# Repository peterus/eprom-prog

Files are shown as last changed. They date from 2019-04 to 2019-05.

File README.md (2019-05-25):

# EPROM Burner

Here you will find the circuit and the source code for a EPROM burner/programer.
This project can be used to program the famous 27/27Cxxx EPROM family.
With this circuit and software you will be able to write and read from an EPROM.

Additional to the provided hardware you will need a Arduino MEGA.
The provided circuit is easy to solder by our own with through hole components - no SMD soldering required!
I have some spare PCBs, you can contact me to get some.

## schematic

You can find the Eagle schematic in the 'schematic' folder.
Aditional you will need a Arduino MEGA board.

## source code

The source code can be found in the folder 'src', 'AVRhal' and some test-programs in 'test'.
The build system is cmake.

### compile

To compile the source code follow this steps:

   mkdir build && cd build
   cmake ..
   make
   
### flash the AVR/Arduino

   make upload_EPROM-PROG

## supported EPROMs

- 27C16 (not tested)
- 27C32 (not tested)
- 27C64 (not tested)
- 27C128 (not tested)
- 27C256 (not tested)
- 27C512 (not tested)
- 27C1001 (not tested)
- 27C2001 (not tested)
- 27C4001 (not tested)
- 27C801 (not tested)

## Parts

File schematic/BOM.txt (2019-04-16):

Stückliste exportiert aus /home/pbuchegger/project/eprom-prog/schematic/eprom_prog.sch am 16.04.19 19:44

Part         Value               Device              Package              Description                          MF MPN               OC_FARNELL OC_NEWARK
B1           ARDUINO_MEGA_R3FULL ARDUINO_MEGA_R3FULL ARDUINO_MEGA_NO_SILK Arduino Mega R3                                                               
C1           100n                C-EU050-024X044     C050-024X044         CAPACITOR, European symbol                                                    
C2           220uF               CPOL-EUE2.5-6       E2,5-6               POLARIZED CAPACITOR, European symbol                                          
C3           100n                C-EU050-024X044     C050-024X044         CAPACITOR, European symbol                                                    
C4           220uF               CPOL-EUE2.5-6       E2,5-6               POLARIZED CAPACITOR, European symbol                                          
C5           750p                C-EU050-024X044     C050-024X044         CAPACITOR, European symbol                                                    
C6           220uF               CPOL-EUE2.5-6       E2,5-6               POLARIZED CAPACITOR, European symbol                                          
D1           1N4148              1N4148DO35-7        DO35-7               DIODE                                                                         
D2           1N4148              1N4148DO35-7        DO35-7               DIODE                                                                         
D3           1N4148              1N4148DO35-7        DO35-7               DIODE                                                                         
D4           1N4148              1N4148DO35-7        DO35-7               DIODE                                                                         
D5           1N5819-B            1N5819-B            DO41-7.6             1.0A SCHOTTKY BARRIER RECTIFIER                                               
D6           1N4148              1N4148DO35-7        DO35-7               DIODE                                                                         
D7           1N4148              1N4148DO35-7        DO35-7               DIODE                                                                         
GOLD_ORB_SM1 OSHWLOGOLOGO8MM     OSHWLOGOLOGO8MM     OSHW_8MM             The OSHW logo for PCB layout                                                  
IC1          MC33063/MC34063P    MC33063/MC34063P    DIL08                MC33063 and MC34063                                                           
K1           G5V1                G5V1                G5V1                 RELAY                                   G5V-1-DC24        9949593    36M6377  
K2           G5V1                G5V1                G5V1                 RELAY                                   G5V-1-DC24        9949593    36M6377  
K3           G5V1                G5V1                G5V1                 RELAY                                   G5V-1-DC24        9949593    36M6377  
K4           G5V1                G5V1                G5V1                 RELAY                                   G5V-1-DC24        9949593    36M6377  
K5           G5V1                G5V1                G5V1                 RELAY                                   G5V-1-DC24        9949593    36M6377  
K6           G5V1                G5V1                G5V1                 RELAY                                   G5V-1-DC24        9949593    36M6377  
L1           220uH               SD12-1000           SD12_1000            INDUCTOR                                                  unknown    unknown  
Q1           BS170               BS170               SOT54E               N-CHANNEL MOS FET                                                             
Q2           BS170               BS170               SOT54E               N-CHANNEL MOS FET                                                             
Q3           BS170               BS170               SOT54E               N-CHANNEL MOS FET                                                             
Q4           BS170               BS170               SOT54E               N-CHANNEL MOS FET                                                             
Q5           BS170               BS170               SOT54E               N-CHANNEL MOS FET                                                             
Q6           BS170               BS170               SOT54E               N-CHANNEL MOS FET                                                             
Q7           BC557               BC557               TO92                 PNP Transistor                                                                
Q8           BS170               BS170               SOT54E               N-CHANNEL MOS FET                                                             
Q9           BS170               BS170               SOT54E               N-CHANNEL MOS FET                                                             
R1           3k3                 R-EU_0207/2V        0207/2V              RESISTOR, European symbol                                                     
R2           3k3                 R-EU_0207/2V        0207/2V              RESISTOR, European symbol                                                     
R3           3k3                 R-EU_0207/2V        0207/2V              RESISTOR, European symbol                                                     
R4           620                 R-EU_0207/2V        0207/2V              RESISTOR, European symbol                                                     
R5           180                 R-EU_0207/2V        0207/2V              RESISTOR, European symbol                                                     
R6           3k3                 R-EU_0207/2V        0207/2V              RESISTOR, European symbol                                                     
R7           3k3                 R-EU_0207/2V        0207/2V              RESISTOR, European symbol                                                     
R8           0.3                 R-EU_0207/2V        0207/2V              RESISTOR, European symbol                                                     
R9           3k3                 R-EU_0207/2V        0207/2V              RESISTOR, European symbol                                                     
R10          300                 R-EU_0207/2V        0207/2V              RESISTOR, European symbol                                                     
R11          1k5                 R-EU_0207/2V        0207/2V              RESISTOR, European symbol                                                     
R12          3k9                 R-EU_0207/2V        0207/2V              RESISTOR, European symbol                                                     
R13          4k7                 R-EU_0207/2V        0207/2V              RESISTOR, European symbol                                                     
R14          4k7                 R-EU_0207/2V        0207/2V              RESISTOR, European symbol                                                     
R15          3k3                 R-EU_0207/2V        0207/2V              RESISTOR, European symbol                                                     
R16          3k3                 R-EU_0207/2V        0207/2V              RESISTOR, European symbol                                                     
T1           BC547               BC547               TO92                 NPN TRANSISTOR                                                                
ZX1          232-1285-00-0602J   232-1285-00-0602J   232-1285-00-0602J    Zero Insertion Force Socked          3M 232-1285-00-0602J 9897402    85K7839

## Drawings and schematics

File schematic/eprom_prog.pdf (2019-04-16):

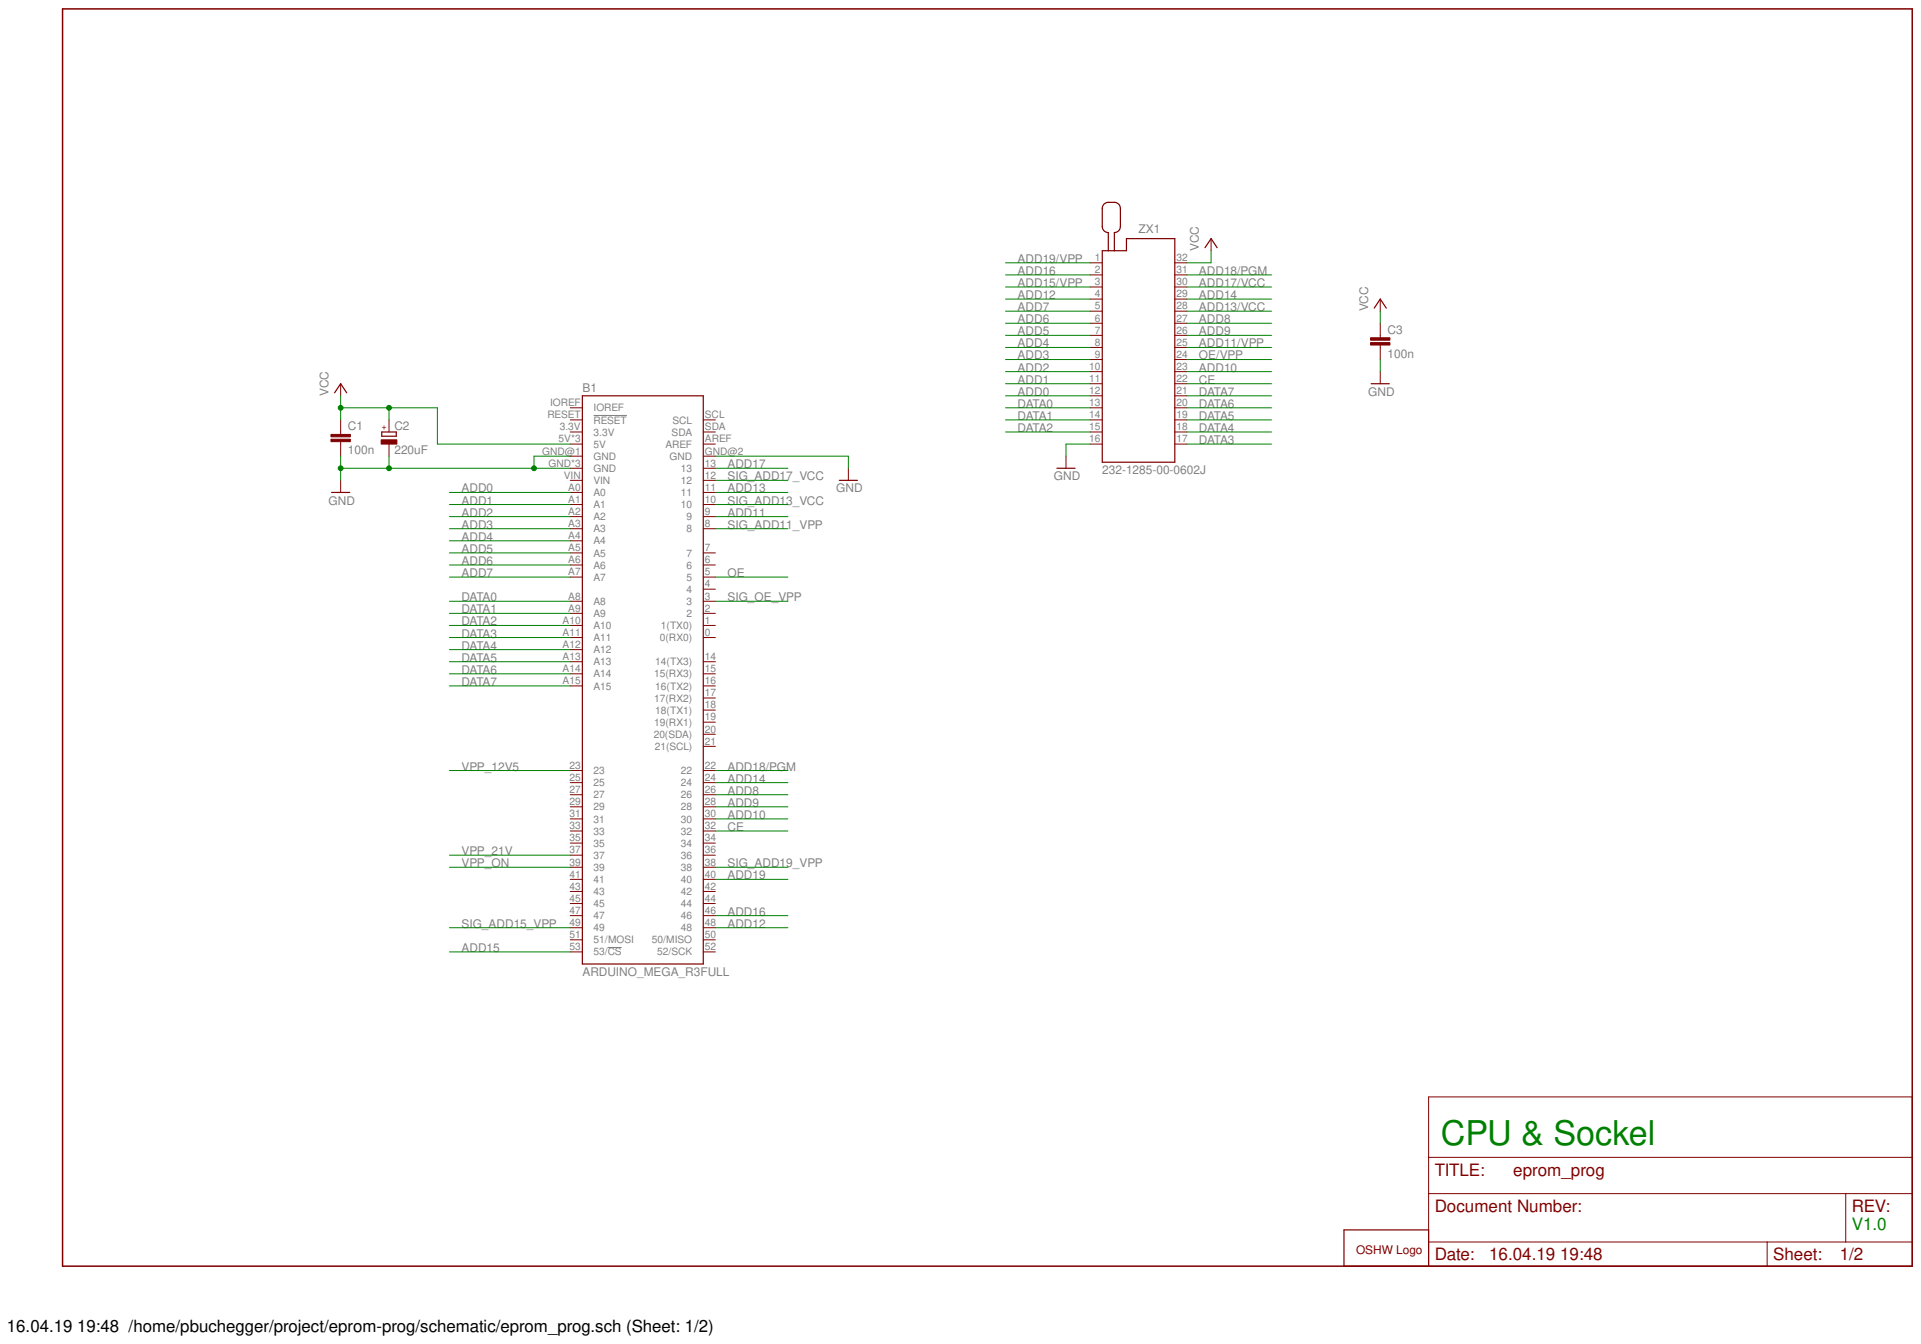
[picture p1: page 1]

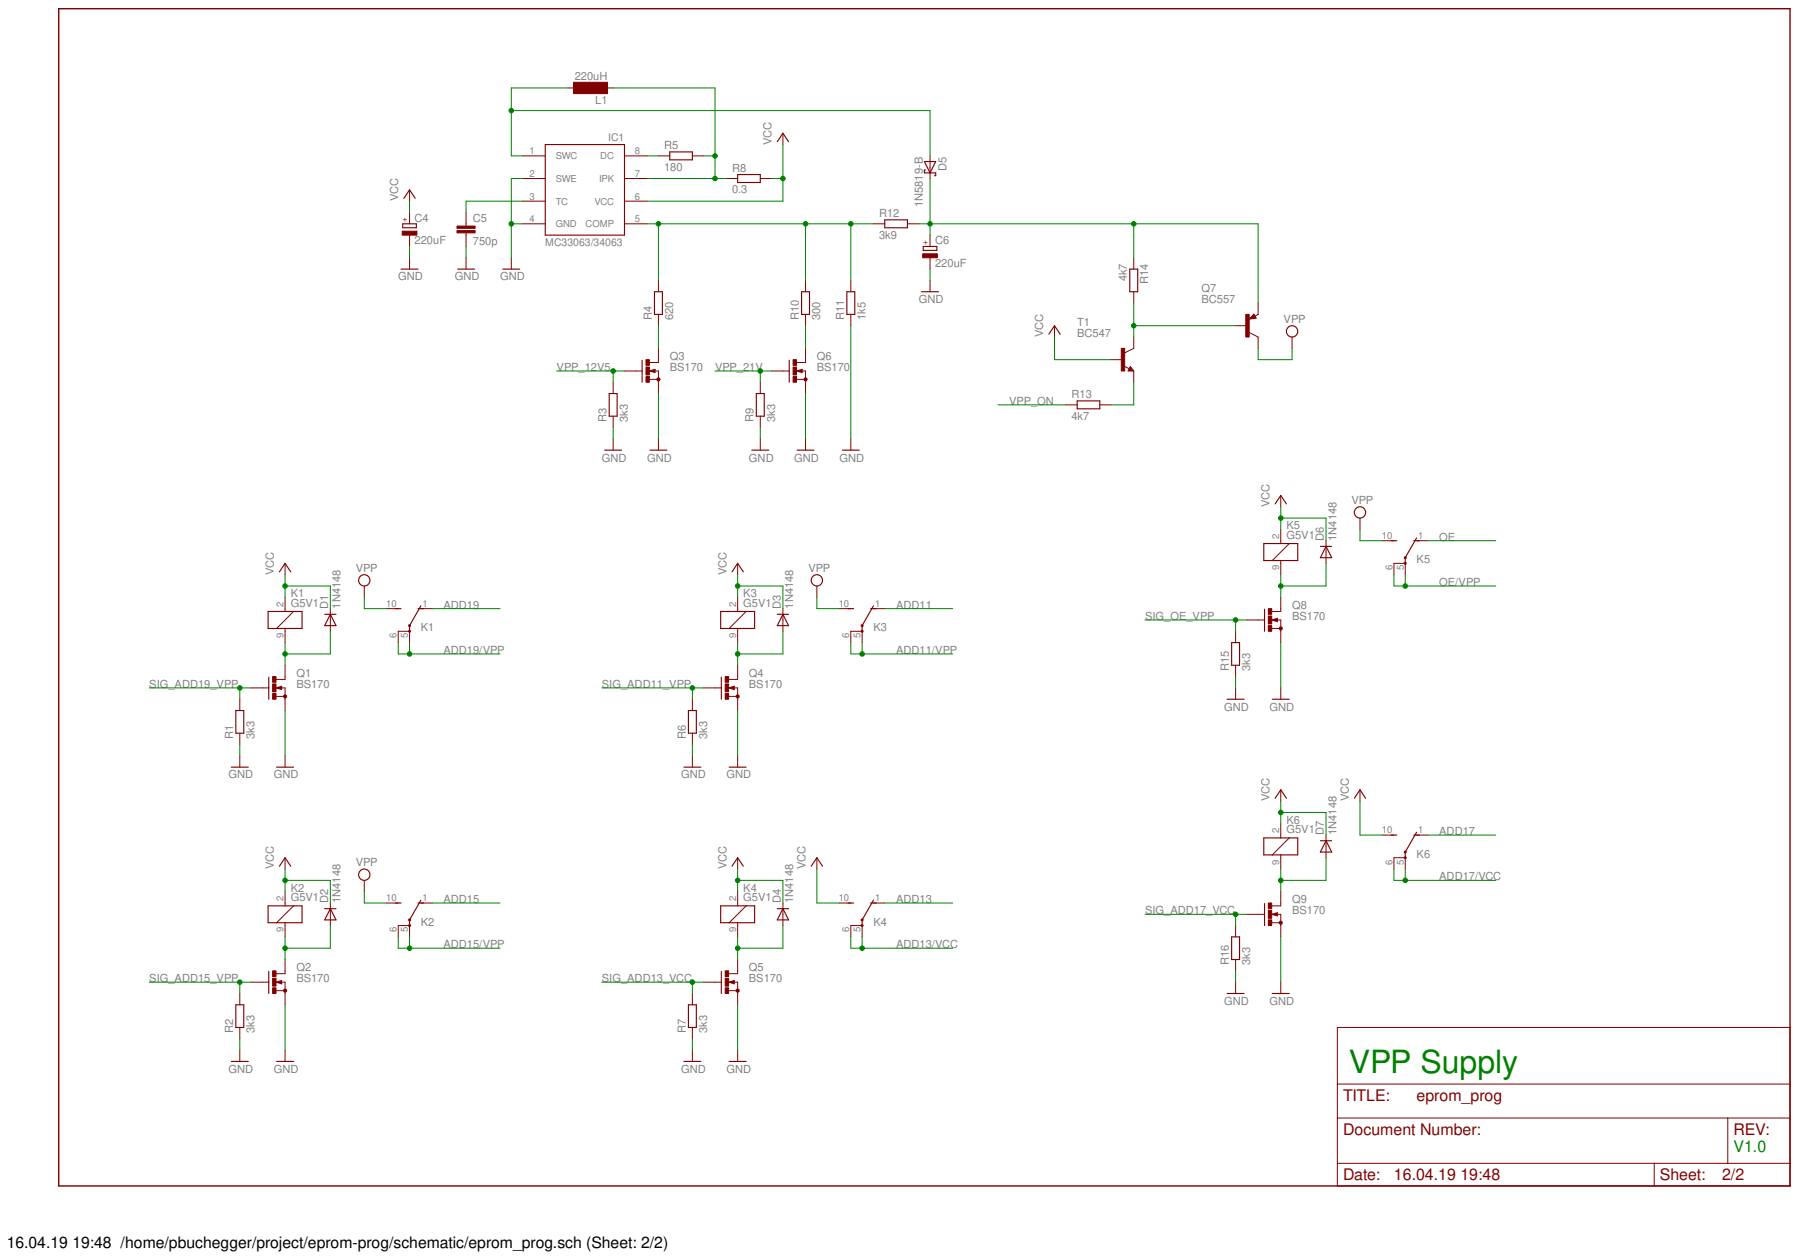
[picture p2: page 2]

Document Number: | REV: V1.0

Date: 16.04.19 19:48 | Sheet: 2/2

16.04.19 19:48 /home/pbuchegger/project/eprom-prog/schematic/eprom_prog.sch (Sheet: 2/2)

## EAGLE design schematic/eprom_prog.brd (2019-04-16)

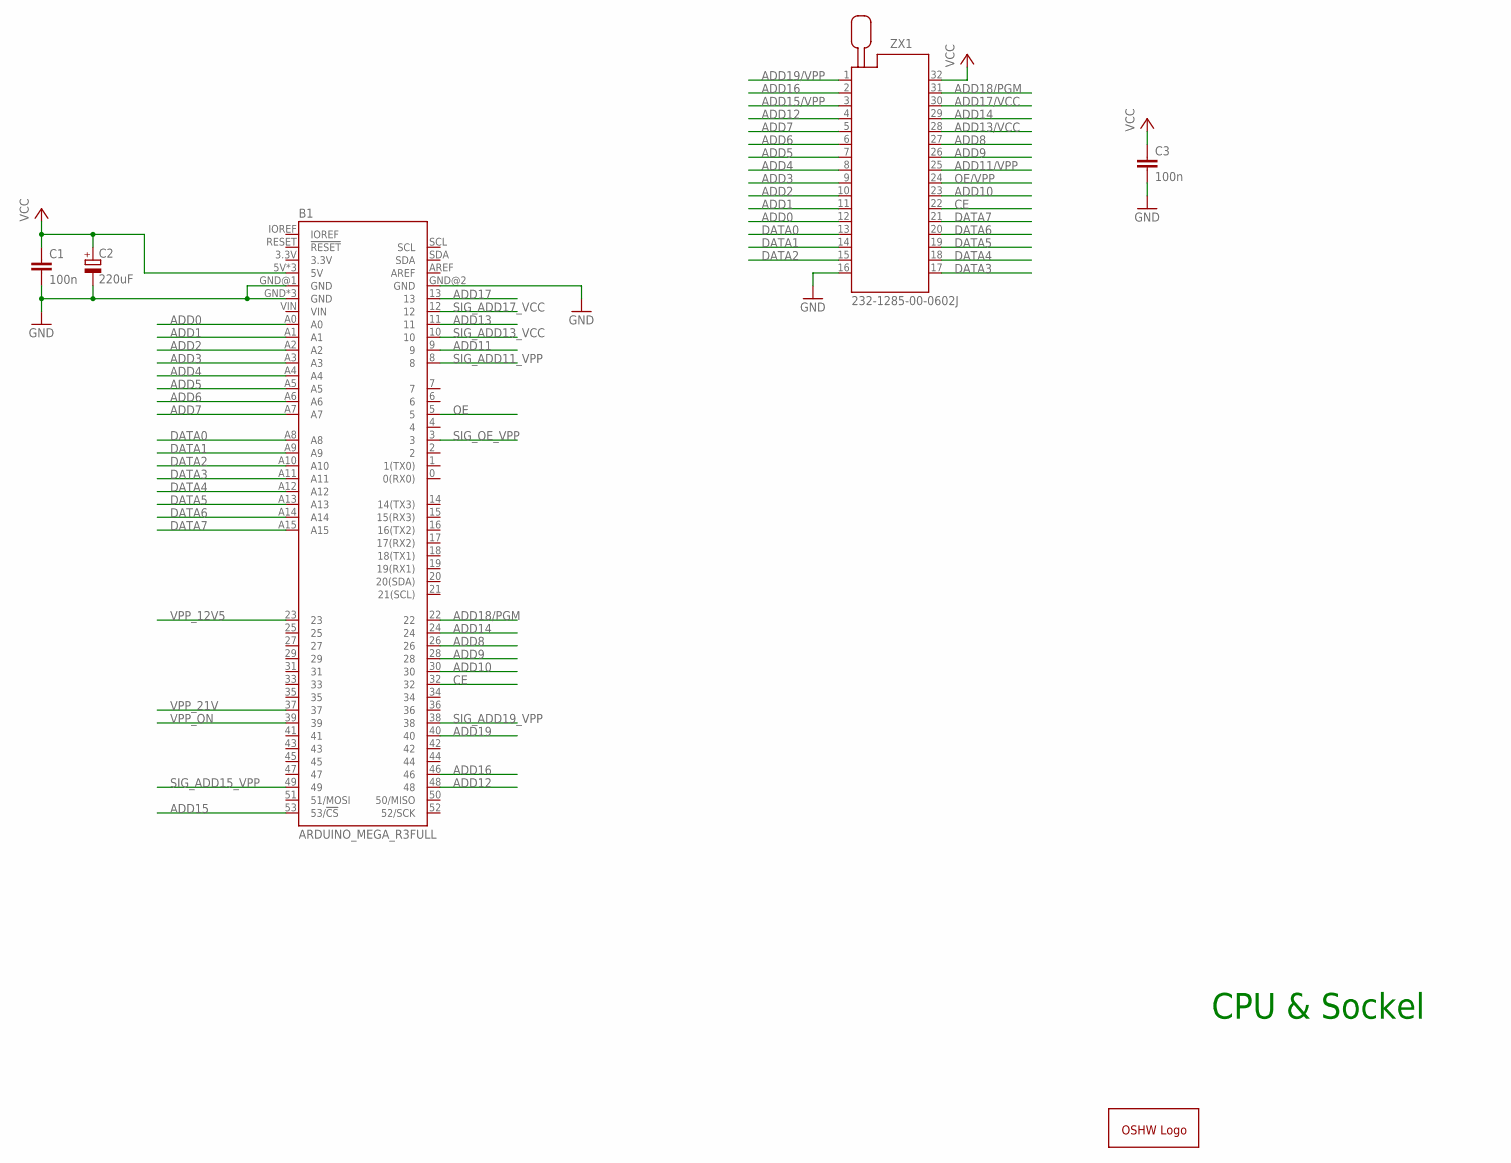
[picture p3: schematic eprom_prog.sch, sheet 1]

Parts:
B1: ARDUINO_MEGA_R3FULL; ARDUINO_MEGA_NO_SILK
C1, C3: 100n; C050-024X044
C2: 220uF; E2,5-6
GOLD_ORB_SM1: OSHWLOGOLOGO8MM; OSHW_8MM
ZX1: 232-1285-00-0602J

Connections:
ADD0: B1.A0, ZX1.12
ADD1: B1.A1, ZX1.11
ADD2: B1.A2, ZX1.10
ADD3: B1.A3, ZX1.9
ADD4: B1.A4, ZX1.8
ADD5: B1.A5, ZX1.7
ADD6: B1.A6, ZX1.6
ADD7: B1.A7, ZX1.5
ADD8: B1.26, ZX1.27
ADD9: B1.28, ZX1.26
ADD10: B1.30, ZX1.23
ADD11: B1.9; also elsewhere on the board
ADD11/VPP: ZX1.25; also elsewhere on the board
ADD12: B1.48, ZX1.4
ADD13: B1.11; also elsewhere on the board
ADD13/VCC: ZX1.28; also elsewhere on the board
ADD14: B1.24, ZX1.29
ADD15: B1.53 (53/!CS); also elsewhere on the board
ADD15/VPP: ZX1.3; also elsewhere on the board
ADD16: B1.46, ZX1.2
ADD17: B1.13; also elsewhere on the board
ADD17/VCC: ZX1.30; also elsewhere on the board
ADD18/PGM: B1.22, ZX1.31
ADD19: B1.40; also elsewhere on the board
ADD19/VPP: ZX1.1; also elsewhere on the board
CE: B1.32, ZX1.22
DATA0: B1.A8, ZX1.13
DATA1: B1.A9, ZX1.14
DATA2: B1.A10, ZX1.15
DATA3: B1.A11, ZX1.17
DATA4: B1.A12, ZX1.18
DATA5: B1.A13, ZX1.19
DATA6: B1.A14, ZX1.20
DATA7: B1.A15, ZX1.21
GND: B1.GND, B1.GND@1 (GND), B1.GND@2 (GND), B1.GND@3 (GND), B1.GND@4 (GND), C1.2, C2.-, C3.2, ZX1.16; also elsewhere on the board
OE: B1.5; also elsewhere on the board
OE/VPP: ZX1.24; also elsewhere on the board
SIG_ADD11_VPP: B1.8; also elsewhere on the board
SIG_ADD13_VCC: B1.10; also elsewhere on the board
SIG_ADD15_VPP: B1.49; also elsewhere on the board
SIG_ADD17_VCC: B1.12; also elsewhere on the board
SIG_ADD19_VPP: B1.38; also elsewhere on the board
SIG_OE_VPP: B1.3; also elsewhere on the board
VCC: B1.5V, B1.5V@1 (5V), B1.5V@2 (5V), C1.1, C2.+, C3.1, ZX1.32; also elsewhere on the board
VPP_12V5: B1.23; also elsewhere on the board
VPP_21V: B1.37; also elsewhere on the board
VPP_ON: B1.39; also elsewhere on the board

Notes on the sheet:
CPU & Sockel

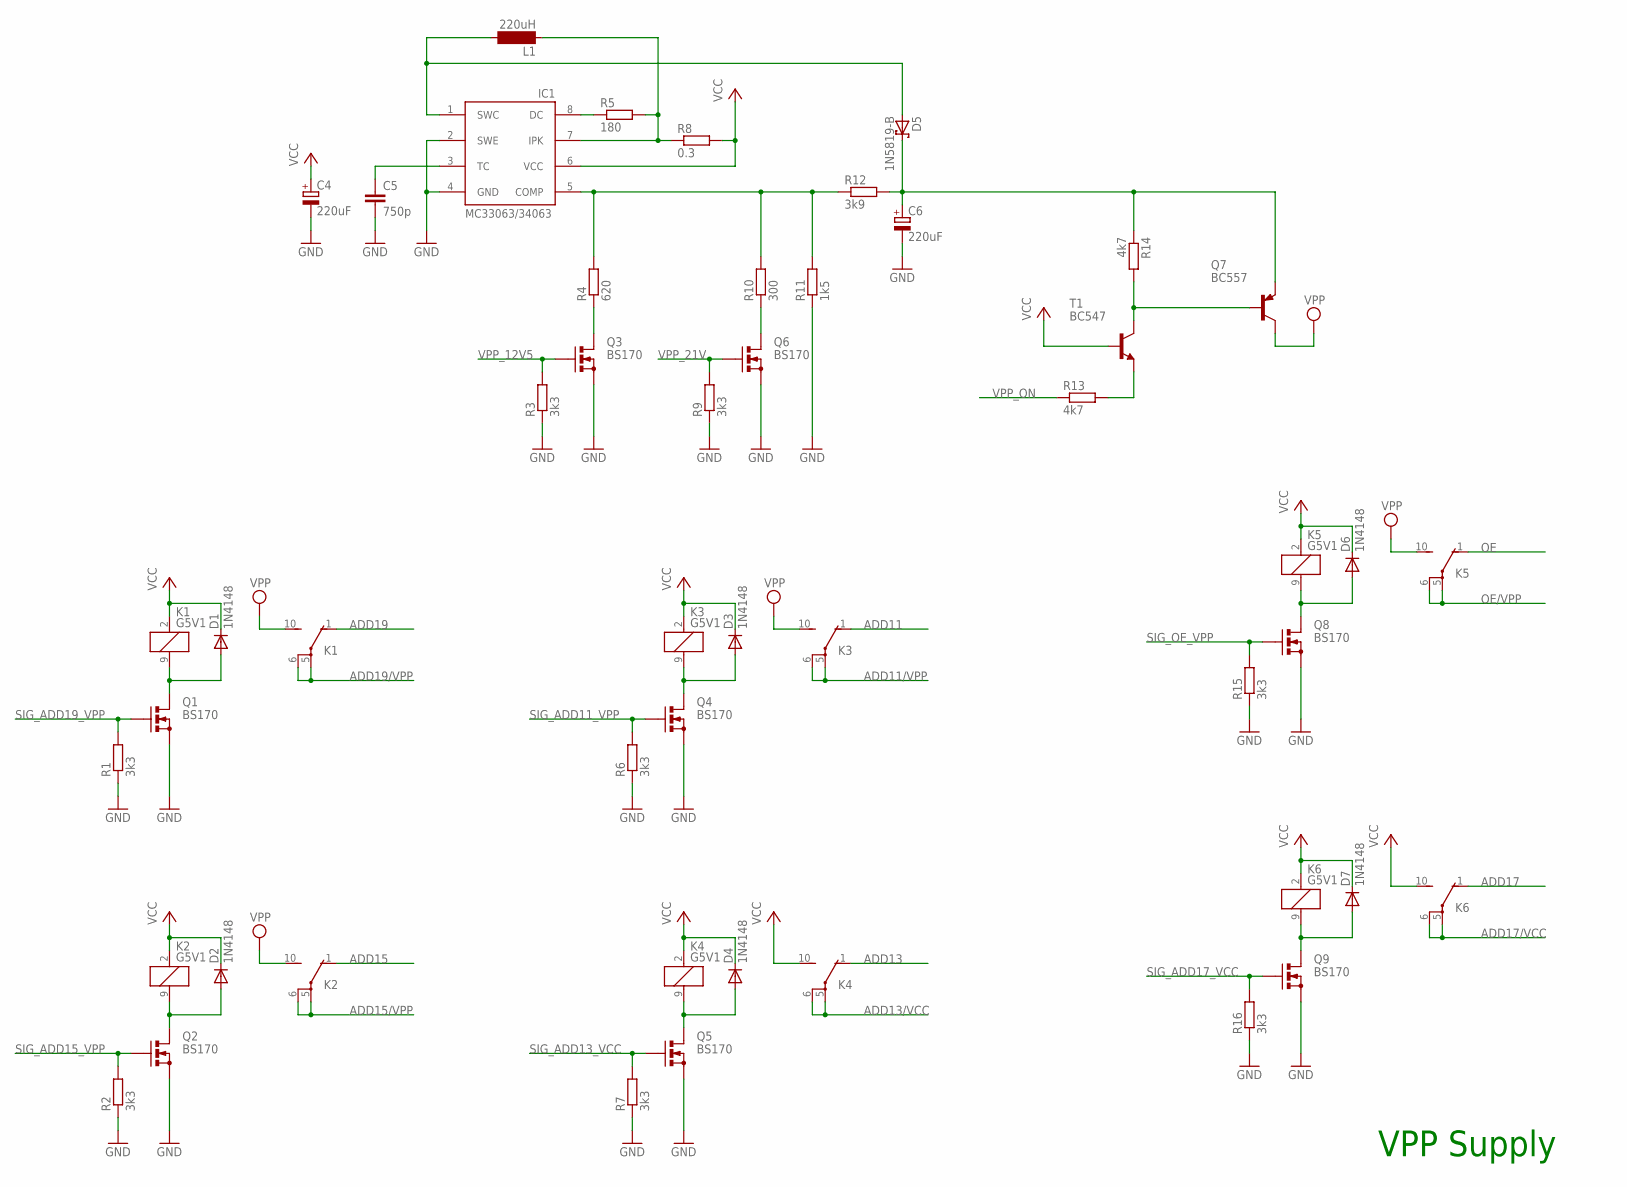
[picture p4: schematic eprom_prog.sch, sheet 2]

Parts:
C4, C6: 220uF; E2,5-6
C5: 750p; C050-024X044
D1, D2, D3, D4, D6, D7: 1N4148; DO35-7
D5: 1N5819-B; DO41-7.6
IC1: MC33063/MC34063P; DIL08
K1, K2, K3, K4, K5, K6: G5V1
L1: 220uH; SD12_1000
Q1, Q2, Q3, Q4, Q5, Q6, Q8, Q9: BS170; SOT54E
Q7: BC557; TO92
R1, R2, R3, R6, R7, R9, R15, R16: 3k3; 0207/2V
R4: 620; 0207/2V
R5: 180; 0207/2V
R8: 0.3; 0207/2V
R10: 300; 0207/2V
R11: 1k5; 0207/2V
R12: 3k9; 0207/2V
R13, R14: 4k7; 0207/2V
T1: BC547; TO92

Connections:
+VPP: C6.+, D5.C, Q7.1 (E), R12.2, R14.1
ADD11: K3.1 (O); also elsewhere on the board
ADD11/VPP: K3.5, K3.6; also elsewhere on the board
ADD13: K4.1 (O); also elsewhere on the board
ADD13/VCC: K4.5, K4.6; also elsewhere on the board
ADD15: K2.1 (O); also elsewhere on the board
ADD15/VPP: K2.5, K2.6; also elsewhere on the board
ADD17: K6.1 (O); also elsewhere on the board
ADD17/VCC: K6.5, K6.6; also elsewhere on the board
ADD19: K1.1 (O); also elsewhere on the board
ADD19/VPP: K1.5, K1.6; also elsewhere on the board
GND: C4.-, C5.2, C6.-, IC1.2 (SWE), IC1.4 (GND), Q1.S, Q2.S, Q3.S, Q4.S, Q5.S, Q6.S, Q8.S, Q9.S, R1.1, R2.1, R3.1, R6.1, R7.1, R9.1, R11.1, R15.1, R16.1; also elsewhere on the board
unnamed: D2.A, K2.9 (2), Q2.D
unnamed: IC1.7 (IPK), L1.1, R5.2, R8.1
unnamed: Q6.D, R10.1
unnamed: Q7.2 (B), R14.2, T1.3 (C)
unnamed: R13.2, T1.1 (E)
unnamed: Q3.D, R4.1
unnamed: C5.1, IC1.3 (TC)
unnamed: IC1.5 (COMP), R4.2, R10.2, R11.2, R12.1
unnamed: IC1.8 (DC), R5.1
unnamed: D5.A, IC1.1 (SWC), L1.2
unnamed: D1.A, K1.9 (2), Q1.D
unnamed: D3.A, K3.9 (2), Q4.D
unnamed: D4.A, K4.9 (2), Q5.D
unnamed: D6.A, K5.9 (2), Q8.D
unnamed: D7.A, K6.9 (2), Q9.D
OE: K5.1 (O); also elsewhere on the board
OE/VPP: K5.5, K5.6; also elsewhere on the board
SIG_ADD11_VPP: Q4.G, R6.2; also elsewhere on the board
SIG_ADD13_VCC: Q5.G, R7.2; also elsewhere on the board
SIG_ADD15_VPP: Q2.G, R2.2; also elsewhere on the board
SIG_ADD17_VCC: Q9.G, R16.2; also elsewhere on the board
SIG_ADD19_VPP: Q1.G, R1.2; also elsewhere on the board
SIG_OE_VPP: Q8.G, R15.2; also elsewhere on the board
VCC: C4.+, D1.C, D2.C, D3.C, D4.C, D6.C, D7.C, IC1.6 (VCC), K1.2 (1), K2.2 (1), K3.2 (1), K4.2 (1), K4.10 (S), K5.2 (1), K6.2 (1), K6.10 (S), R8.2, T1.2 (B); also elsewhere on the board
VPP: K1.10 (S), K2.10 (S), K3.10 (S), K5.10 (S), Q7.3 (C)
VPP_12V5: Q3.G, R3.2; also elsewhere on the board
VPP_21V: Q6.G, R9.2; also elsewhere on the board
VPP_ON: R13.1; also elsewhere on the board

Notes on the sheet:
VPP Supply

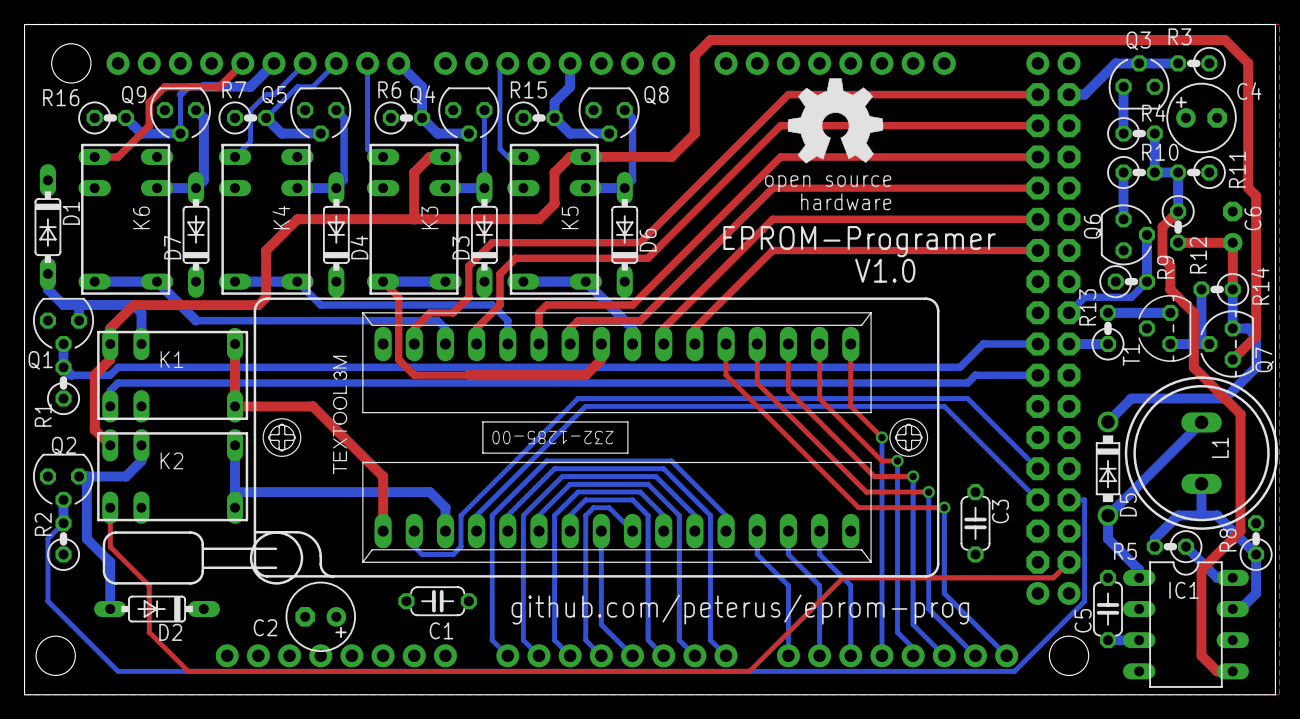
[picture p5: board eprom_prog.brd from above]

Board: 2 copper layers, 101.9 x 54.6 mm, 50 parts (1 on the bottom side), 64 nets.

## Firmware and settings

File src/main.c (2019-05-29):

/*
 * UART_Test.c
 *
 * Created: 26.10.2014 19:01:09
 *  Author: Peter Buchegger
 */ 


#include <stdint.h>
#include <stdio.h>
#include <util/delay.h>
#include "COM/UART.h"
#define _DEBUG
#include "Debug.h"
#include "System.h"

#include "io.h"
#include "27c.h"

/*************************************
---> set eprom type
1. byte: 0x01
2. byte: enum EPROM_Type { 801 = 0, 4001 = 1, 2001 = 2, 1001 = 3, 512 = 4, 256 = 5, 128 = 6, 64 = 7, 32 = 8, 16 = 9 }
3. byte: enum EPROM_VPP { 12.5V = 0, 21V = 1 }

---> set address
1. byte: 0x02
2. byte: address (higher byte)
3. byte: address (lower byte)

---> read data (with address increment)
1. byte: 0x03
2. byte: length to read in bytes

---> write data (with address increment)
1. byte 0x04
2. byte: length to write
x. byte: data

all answers are:
1. byte: 0x1.
other bytes are the same as sent
*************************************/

eprom_setting_t * eprom_setting = 0;
uint32_t address = 0;

void set_eprom_type(void)
{
	unsigned int type = 0;
	unsigned int vpp = 0;
	while((type = UART_GetC()) == UART_NO_DATA) {} // 2. byte: type
	eprom_setting = eprom_settings[type];
	
	while((vpp = UART_GetC()) == UART_NO_DATA) {} // 3. byte: vpp
	eprom_setting->vpp_power = vpp;

	address_map.size = eprom_setting->address_pins_count;
	printf("selected chip: %s\n", eprom_setting->name);

	reset_all();
	setup_power(eprom_setting);
	setup_relay(eprom_setting);
	sleep(100);

	UART_PutByte(0x11);
	UART_PutByte((uint8_t)type);
	UART_PutByte((uint8_t)vpp);
}

void set_address(void)
{
	uint8_t upper = 0;
	uint8_t lower = 0;
	unsigned int buffer = 0;
	while((buffer = UART_GetC()) == UART_NO_DATA) {} // 2. byte: address (higher byte)
	upper = buffer & 0xFF;
	while((buffer = UART_GetC()) == UART_NO_DATA) {} // 3. byte: address (lower byte)
	lower = buffer & 0xFF;

	address = upper << 8 | lower;

	UART_PutByte(0x12);
	UART_PutByte(upper);
	UART_PutByte(lower);
}

void read_data_(void)
{
	uint16_t length = 0;
	uint8_t upper = 0;
	uint8_t lower = 0;
	unsigned int buffer = 0;

	while((buffer = UART_GetC()) == UART_NO_DATA) {} // 2. byte: length (higher byte)
	upper = buffer & 0xFF;
	while((buffer = UART_GetC()) == UART_NO_DATA) {} // 3. byte: length (lower byte)
	lower = buffer & 0xFF;

	length = upper << 8 | lower;

	UART_PutByte(0x13);
	read_data_start(eprom_setting);
	for(uint16_t i = 0; i < length; i++)
	{
		uint32_t data = read_data(eprom_setting, address);
		UART_PutByte((uint8_t)data);
		address++;
	}
	read_data_end(eprom_setting);
}

void write_data_start(void)
{
	program_data_start(eprom_setting);
	UART_PutByte(0x14);
}

void write_data_(void)
{
	uint16_t length = 0;
	uint8_t upper = 0;
	uint8_t lower = 0;
	unsigned int buffer = 0;

	while((buffer = UART_GetC()) == UART_NO_DATA) {} // 2. byte: length (higher byte)
	upper = buffer & 0xFF;
	while((buffer = UART_GetC()) == UART_NO_DATA) {} // 3. byte: length (lower byte)
	lower = buffer & 0xFF;

	length = upper << 8 | lower;

	UART_PutByte(0x15);
	UART_PutByte(upper);
	UART_PutByte(lower);
	for(uint16_t i = 0; i < length; i++)
	{
		unsigned int data = 0;
		while((data = UART_GetC()) == UART_NO_DATA) {} // x. byte: data
		program_data(eprom_setting, address, (uint8_t)data);
		UART_PutByte((uint8_t)data);
		address++;
	}
}

void write_data_end(void)
{
	program_data_end(eprom_setting);
	UART_PutByte(0x16);
}

void verify_empty(void)
{
	uint8_t status = 0;
	read_data_start(eprom_setting);
	for(uint32_t i = 0; i < eprom_setting->max_data; i++)
	{
		uint32_t data = read_data(eprom_setting, i);
		if(data != 0xFF)
		{
			status = 1;
		}
	}
	read_data_end(eprom_setting);
	UART_PutByte(0x17);
	UART_PutByte(status);
}

int main(void)
{
	// 19200
	// 57600
	// 115200
	UART_Init(UART_BAUD_SELECT(57600, F_CPU));
	interrupts(1); //sei();

	reset_all();
	DEBUG_OUT("ready\n");
	
	while(1)
	{
		unsigned int c = 0;
		while((c = UART_GetC()) == UART_NO_DATA) {}

		switch(c)
		{
			case 0x01:
				set_eprom_type();
				break;
			case 0x02:
				set_address();
				break;
			case 0x03:
				read_data_();
				break;
			case 0x04:
				write_data_start();
				break;
			case 0x05:
				write_data_();
				break;
			case 0x06:
				write_data_end();
				break;
			case 0x07:
				verify_empty();
			default:
				break;
		}
	}
}

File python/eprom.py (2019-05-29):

#!/bin/python

import serial
import argparse

DEBUG = 0

eprom_settings = [
	{'name': '27C801',  'size': 2**20, 'id': 0},
	{'name': '27C4001', 'size': 2**19, 'id': 1},
	{'name': '27C2001', 'size': 2**18, 'id': 2},
	{'name': '27C1001', 'size': 2**17, 'id': 3},
	{'name': '27C512',  'size': 2**16, 'id': 4},
	{'name': '27C256',  'size': 2**15, 'id': 5},
	{'name': '27C128',  'size': 2**14, 'id': 6},
	{'name': '27C64',   'size': 2**13, 'id': 7},
	{'name': '27C32',   'size': 2**12, 'id': 8},
	{'name': '27C16',   'size': 2**11, 'id': 9}
]

def set_type(ser, type, vpp):
	print("set type:")
	values = bytearray([0x01, type, vpp])
	ser.write(values)
	print(ser.readline())
	s = ser.read(3)
	if DEBUG == 1:
		for key, x in enumerate(s):
			print("%i: 0x%0.2X" % (key, x))
	if s[0] != 0x11 or s[1] != type or s[2] != vpp:
		raise Exception('set_type', 'readback is not okay')

def set_address(ser, address):
	print("set address:")
	upper = (address >> 8) & 0xFF
	lower = address & 0xFF
	values = bytearray([0x02, upper, lower])
	ser.write(values)
	s = ser.read(3)
	if DEBUG == 1:
		for key, x in enumerate(s):
			print("%i: 0x%0.2X" % (key, x))
	if s[0] != 0x12 or s[1] != upper or s[2] != lower:
		raise Exception('set_address', 'readback is not okay')

def read_data(ser, length):
	#print("read data:")
	upper = (length >> 8) & 0xFF
	lower = length & 0xFF
	values = bytearray([0x03, upper, lower])
	ser.write(values)
	s = ser.read(length+1)
	if DEBUG == 1:
		for key, x in enumerate(s):
			print("%i: 0x%0.2X" % (key, x))
	if s[0] != 0x13:
		raise Exception('read_data', 'readback is not okay')
	return s[1:]

def write_data_start(ser):
	print("write data start:")
	values = bytearray([0x04])
	ser.write(values)
	s = ser.read(1)
	if DEBUG == 1:
		for key, x in enumerate(s):
			print("%i: 0x%0.2X" % (key, x))
	if s[0] != 0x14:
		raise Exception('write_data_start', 'readback is not okay')

def write_data(ser, data):
	length = len(data)
	upper = (length >> 8) & 0xFF
	lower = length & 0xFF
	values = bytearray([0x05, upper, lower]) + data
	#print(values)
	ser.write(values)
	s = ser.read(length+3)
	if DEBUG == 1:
		for key, x in enumerate(s):
			print("%i: 0x%0.2X" % (key, x))
	if s[0] != 0x15 or s[1] != upper or s[2] != lower:
		raise Exception('write_data', 'readback is not okay')

def write_data_end(ser):
	print("write data end:")
	values = bytearray([0x06])
	ser.write(values)
	s = ser.read(1)
	if DEBUG == 1:
		for key, x in enumerate(s):
			print("%i: 0x%0.2X" % (key, x))
	if s[0] != 0x16:
		raise Exception('write_data_end', 'readback is not okay')

def verify(ser):
	print("verify empty:")
	values = bytearray([0x07])
	ser.write(values)
	s = ser.read(2)
	if DEBUG == 1:
		for key, x in enumerate(s):
			print("%i: 0x%0.2X" % (key, x))
	if s[0] != 0x17:
		raise Exception('verify', 'readback is not okay')
	return s[1]

def get_eprom_type(eprom):
	for e in eprom_settings:
		if eprom == e['name']:
			return e
	die("wrong EPROM selected")

def read_file(file_name, port, eprom):
	with open(file_name, "wb") as file:
		print(ser.name)
		line = ser.readline()
		print(line)

		set_type(ser, eprom['id'], 0)
		set_address(ser, 0)
		data_count = 0
		size = 1024
		for i in range(0, eprom['size'], size):
			data = read_data(ser, size)
			data_count = data_count + size
			#print(data)
			file.write(data)
			percent = data_count / eprom['size'] * 100
			print("read %d from %d bytes: %.2f%%" % (data_count, eprom['size'], percent))


def write_file(file_name, port, eprom):
	with open(file_name, "rb") as file:
		print(ser.name)
		line = ser.readline()
		print(line)

		set_type(ser, eprom['id'], 0)
		set_address(ser, 0)
		write_data_start(ser)
		data_count = 0
		size = 126
		for i in range(0, eprom['size'], size):
			data = file.read(size)
			#print(data)
			write_data(ser, data)
			data_count = data_count + size
			percent = data_count / eprom['size'] * 100
			print("write %d from %d bytes: %.2f%%" % (data_count, eprom['size'], percent))
			#break
		write_data_end(ser)

def verify_empty(ser, eprom):
	print(ser.name)
	print(ser.readline())

	set_type(ser, eprom['id'], 0)
	status = verify(ser)
	if status == 0:
		print("Chip is empty!")
	else:
		print("Chip is NOT empty!")


if __name__ == '__main__':
	eproms = []
	for setting in eprom_settings:
		eproms.append(setting['name'])

	parser = argparse.ArgumentParser(description='Write or read from an SRAM to a file.')
	parser.add_argument('-m', '--mode', choices=['read', 'write', 'verify'], help='define if read or write from file.')
	parser.add_argument('--eprom', choices=eproms, help='choose the correct 27C...')
	parser.add_argument('-f', '--file', help='file to read or write.')
	parser.add_argument('-p', '--port', help='serial port for the arduino mega.')

	args = parser.parse_args()
	eprom = get_eprom_type(args.eprom)

	with serial.Serial(args.port, 57600) as ser:
	#with serial.Serial(port, 57600, timeout=1) as ser:
		if args.mode == 'read':
			print("READ")
			read_file(args.file, ser, eprom)
		elif args.mode == 'write':
			print("WRITE")
			write_file(args.file, ser, eprom)
		elif args.mode == 'verify':
			print("VERIFY")
			verify_empty(ser, eprom)

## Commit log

2019-04-16 first upload
    [27pins.xlsx, eprom_prog.brd, eprom_prog.sch]
2019-04-16 schematic: BOM and pdf export
    [eprom_prog.sch]

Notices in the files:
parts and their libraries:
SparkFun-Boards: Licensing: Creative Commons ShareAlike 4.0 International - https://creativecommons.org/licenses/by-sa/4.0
